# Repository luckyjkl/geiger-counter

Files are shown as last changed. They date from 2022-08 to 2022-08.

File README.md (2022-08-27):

# 盖革计数器

盖革管型号SI3BG，这个型号的盖革管价格便宜，量程比较大，灵敏度比较低，所以测量结果仅供参考。

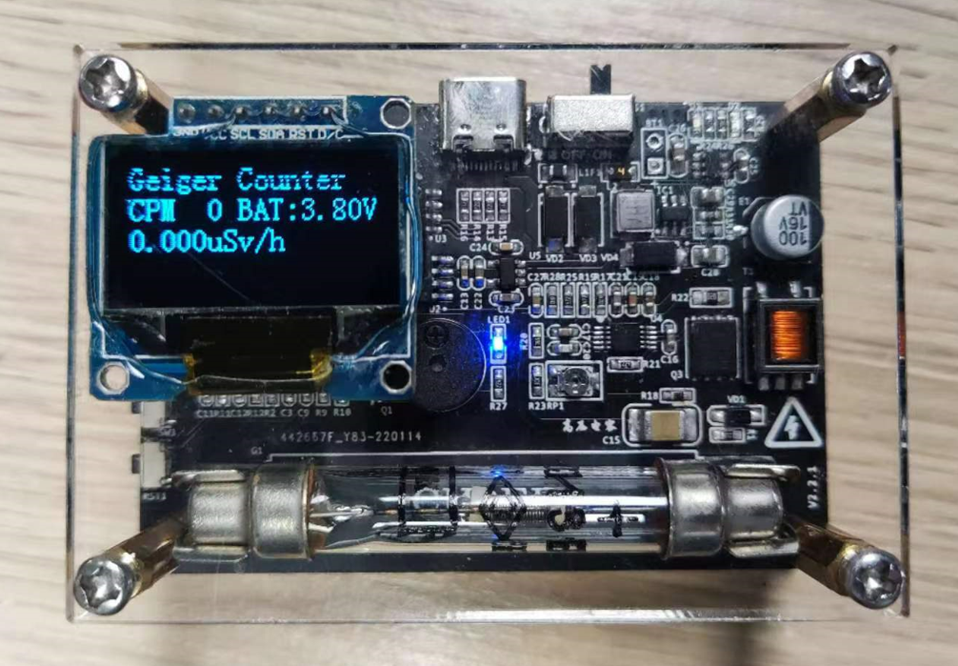
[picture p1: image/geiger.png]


## 1. 工程说明

### 1.1 参考设计

盖革管的测量电路设计参考[https://oshwhub.com/zhaokbk/si3bg_copy_copy](https://oshwhub.com/zhaokbk/si3bg_copy_copy)
盖革管电源驱动部分参考[https://oshwhub.com/zhaokbk/lm3481-gao-xiao-bian-ya-qi-hui-guang-guan-sheng-ya-mu-kuai](https://oshwhub.com/zhaokbk/lm3481-gao-xiao-bian-ya-qi-hui-guang-guan-sheng-ya-mu-kuai)

### 1.2 注意事项

1. OLED屏安装在左上角，屏幕的PCB会和铜柱发生干涉，所以只能将屏幕PCB锯掉一点，因为屏幕已经粘在亚克力板上，所以没有调整位置，介意的可以自行将屏幕右移。
2. 为什么加了一个5V的升压电路给盖革管驱动供电？去掉行不行？因为经过实测，要升压至400V，盖革管驱动部分的输入电压需要在3.8V以上，否则输出无法达到400V，且电压较高驱动电路部分的效率也较高，电压降低时功耗会急剧增大，影响续航。
3. 升压部分MOS管型号怎么选？
   * 选择导通阻抗低的，可以减小功耗。
   * 线圈副边升压至400V，匝数比1：10，所以原边MOS管的反向耐压值应该大于40V
4. 因为要提高盖革管驱动部分的效率，所以添加了一个5V的升压电路，系统不够简介，可以更换一个带5V输出的锂电池充电芯片，简化电路方案。
5. SWDIO口的接口型号为SH1.0-4P

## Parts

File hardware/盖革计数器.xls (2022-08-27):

Comment | Description | Designator | Footprint | LibRef | Quantity
DC5V | 蜂鸣器 | B1 | BEEP 5x9x5.5 | BEEP | 1
Battery 3.7V | Multicell Battery | BT1 | BAT-2 | Battery | 1
22 | 无极性贴片电容 | C1, C2 | C 0603 | C | 2
104 | 无极性贴片电容 | C3, C4, C5, C6, C7, C8, C11, C12, C13, C14, C27 | C 0603 | C | 11
220pF | 无极性贴片电容 | C9 | C 0603 | C | 1
103 | 无极性贴片电容 | C10, C24 | C 0603 | C | 2
1uF | 无极性贴片电容 | C15 | C 1812 | C | 1
1uF | 无极性贴片电容 | C16 | C 0603 | C | 1
22nF | 无极性贴片电容 | C17 | C 0603 | C | 1
100nF | 无极性贴片电容 | C18, C19 | C 0603 | C | 2
10pF | 无极性贴片电容 | C20 | C 0603 | C | 1
1nF | 无极性贴片电容 | C21 | C 0603 | C | 1
105 | 无极性贴片电容 | C22, C23, C25 | C 0603 | C | 3
10uF | 无极性贴片电容 | C26 | C 0805 | C | 1
22uF (226) 20% 25V | 贴片电容 | C28, C29 | 0805_C | 0805 22uF (226) 20% 25V | 2
红灯 0603 | 发光二极管 | D1 | 0603_LED_S1 | 0603 红灯 | 1
绿灯 0603 | 发光二极管 | D2 | 0603_LED_S1 | 0603 绿灯 | 1
100uF/16V | 贴片电解电容 | E1 | CM D(6.3*5.4) | C-CM | 1
0.5A | 贴片保险丝 | F1 | FU 0805 | FU | 1
盖革管 | 小型高量程SI3BG GM管 | G1 | SI3BG 2 | 盖革管 | 1
SX1308 | 可调升压芯片 | IC1 | SOT23-6N | SX1308 | 1
HDR-1X4 | 4P接插件 | JP1 | SH1.0-4P-L | Header 4 | 1
10um | 小功率贴片电感 | L1 | L 0805 | L | 1
4.7uH | 功率屏蔽电感 | L2 | L 04020 | L-CDRH | 1
红色 | 贴片LED | LED1 | LED 0603W | LED-SMD | 1
OLE 0.96-12864-7Pin |  | OLED1 | HDR-1X7_M | OLE 0.96-12864-7Pin | 1
S9013 | 低频放大-NPN型 | Q1, Q2 | SOT23-3N | 9013-SMD | 2
IRFH7440TRPBF | 40V/159A N沟道MOS管 | Q3 | PQFN8_5X6_B_INF | IRFH7440TRPBF | 1
2M | 贴片电阻 | R1 | R 0603 | R | 1
10K | 贴片电阻 | R2, R3, R5, R6, R8, R11, R12 | R 0603 | R | 7
0 | 贴片电阻 | R4 | R 0603 | R | 1
1K | 贴片电阻 | R7, R27, R28 | R 0603 | R | 3
22K | 贴片电阻 | R9 | R 0603 | R | 1
100K | 贴片电阻 | R10 | R 0603 | R | 1
10 | 贴片电阻 | R13, R14 | R 0603 | R | 2
5.1K | 贴片电阻 | R15, R16 | R 0603 | R | 2
121K | 贴片电阻 | R17, R19 | R 0603 | R | 2
10M | 贴片电阻 | R18 | R 0603 | R | 1
40.2K | 贴片电阻 | R20 | R 0603 | R | 1
220K | 贴片电阻 | R21 | R 0603 | R | 1
0.02 | 贴片电阻 | R22 | R 0805 | R | 1
20K | 贴片电阻 | R23 | R 0603 | R | 1
4.7K | 贴片电阻 | R24, R25, R29 | R 0603 | R | 3
3K | 贴片电阻 | R26 | R 0603 | R | 1
110KΩ (1103) ±1% | 贴片电阻 | R30 | 0603_R | 0603 110KΩ (1103) 1% | 1
15KΩ (1502) ±1% | 贴片电阻 | R31 | 0603_R | 0603 15KΩ (1502) 1% | 1
10K | 贴片电位器 | RP1 | 3303W | RP-SMD | 1
TSW | 轻触开关 | RST1, SW1, SW2, SW3 | TSW 2*4*3.5-S-W | TSW SMD | 4
SS-12F23 | 1路拨动开关 | S1 | SS-12D07 | SSW-1P | 1
TTRN-060S-013-T | 1:10.5 3.2A 贴片闪光灯变压器 | T1 | EE5.0 | TTRN-060S-013-T | 1
STM32F103C | STM32单片机48引脚 | U1 | LQFP-48_M | STM32F103C | 1
W25QXX | SPI FLASH | U2 | SOIC8_W | W25QXX | 1
CH330 |  | U3 | SOIC8_N | CH330 | 1
LM3481 | High-Efficiency Controller for Boost, SEPIC and Flyback DC-DC Converters | U4 | VSSOP10 | LM3481 | 1
SGM2028-3.3YN5G | 500mA,3.3V低压差线性稳压器 | U5 | SOT23-5 | SGM2028-3.3YN5G | 1
TP4059 | 600mA单节锂电池充电芯片 | U6 | SOT23-6_N | TP4059 | 1
USB | USB-C型母口16P/12P | USB1 | USB-C/16P | USB-C/16P | 1
E1J | 600V/1A 超快恢复二极管 | VD1 | SOD-123F | E1J | 1
SS54 | 肖特基二极管 | VD2, VD3 | SMA | SS14 | 2
SS34 | 肖特基二极管 | VD4 | SMA | SS14 | 1
8M | 4脚晶振 | X1 | XTAL-3225 | XTAL-4 | 1

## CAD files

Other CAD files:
盖板.dwg

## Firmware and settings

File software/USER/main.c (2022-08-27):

#include "stm32f10x.h"
#include <stdio.h>
#include "oled.h"
#include "pwm.h"
#include "exti.h"
#include "usart.h"
#include "delay.h"
#include "timer.h"
#include "beep.h"
#include "adc.h"
#include "sample_timer.h"

//151CPM=1uSv/h,计数和辐射量转换公式

//extern int Geiger_Count;
//extern int Last_Geiger_Count;
//extern float volatile Count_Time;
extern int volatile Count_Sum;
////float radiation_dose = 0;
//extern char volatile Count_Queue[MAX_QUEUE_LENGTH];

int main()
{
//	u16 volatile pwmval;	
//	pwmval = 13999;
	delay_init();
	uart_init(115200);
	EXTIX_Init();
	NVIC_PriorityGroupConfig(NVIC_PriorityGroup_2);     //设置中断分组
	SPI_OLED_Init();
    Battery_ADC_Init();
	
	TIM3_Init(9999, 719);			//频率100K，计数时间0.1s
    Sample_Timer_Init();
	BEEP_Init();					//蜂鸣器初始化
	
	OLED_ShowString(0, 0, "Geiger Counter");
	OLED_ShowString(0, 2, "CPM");
    
    OLED_ShowNum(24, 2, Count_Sum, 3, 16);
    Show_Radiation_Dose();
    OLED_Show_Voltage();
	
	while(1)
	{
//		OLED_ShowNum(24, 2, Count_Sum, 3, 16);
//		Show_Radiation_Dose();
//		if(Last_Geiger_Count < Geiger_Count)
//		{
//			Last_Geiger_Count = Geiger_Count;
//			BEEP_ON;
//		}
//		delay_ms(100);
//		BEEP_OFF;
//		printf("test\r\n");
	}
}

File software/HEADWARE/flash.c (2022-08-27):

#include "flash.h" 
//#include "spi.h"
#include "delay.h"   
//Mini STM32开发板
//W25X16 驱动函数 
//正点原子@ALIENTEK
//2010/6/13
//V1.0
u16 SPI_FLASH_TYPE=W25Q64;//默认就是25Q64
//4Kbytes为一个Sector
//16个扇区为1个Block
//W25X16
//容量为2M字节,共有32个Block,512个Sector

SPI_InitTypeDef SPI_InitType;

//初始化SPI FLASH的IO口
void SPI_Flash_Init(void)
{
	GPIO_InitTypeDef GPIO_InitStructure;
	SPI_InitTypeDef SPI_InitType;

	RCC_APB2PeriphClockCmd(SPI_FLASH_CS_RCC, ENABLE);

	GPIO_InitStructure.GPIO_Pin = SPI_FLASH_CS;  //SPI CS
 	GPIO_InitStructure.GPIO_Mode = GPIO_Mode_Out_PP;  //复用推挽输出
	GPIO_InitStructure.GPIO_Speed = GPIO_Speed_50MHz;
 	GPIO_Init(SPI_FLASH_CS_GPIO, &GPIO_InitStructure);
 	GPIO_SetBits(SPI_FLASH_CS_GPIO, SPI_FLASH_CS);
	
	RCC_APB2PeriphClockCmd(Flash_GPIO_RCC, ENABLE);		//GPIO,SPI使能
	RCC_APB1PeriphClockCmd(Flash_SPI_RCC, ENABLE);

	GPIO_InitStructure.GPIO_Pin = Flash_SPI_SCK | Flash_SPI_MISO | Flash_SPI_MOSI;
	GPIO_InitStructure.GPIO_Mode = GPIO_Mode_AF_PP;								//复用推挽输出
	GPIO_InitStructure.GPIO_Speed = GPIO_Speed_50MHz;
	GPIO_Init(Flash_SPI_GPIO, &GPIO_InitStructure);									//GPIO初始化
	GPIO_SetBits(Flash_SPI_GPIO, Flash_SPI_SCK | Flash_SPI_MISO | Flash_SPI_MOSI);	//IO输出高
	
	SPI_InitType.SPI_Direction = SPI_Direction_2Lines_FullDuplex;		//SPI设置全双工
	SPI_InitType.SPI_Mode = SPI_Mode_Master;							//SPI设置为主SPI
	SPI_InitType.SPI_CPOL = SPI_CPOL_High;								//稳态时钟高
	SPI_InitType.SPI_CPHA = SPI_CPHA_2Edge;								//数据捕获于第二个时钟沿
	SPI_InitType.SPI_DataSize = SPI_DataSize_8b;						//八位帧结构
	SPI_InitType.SPI_NSS = SPI_NSS_Soft;								//NSS信号由软件控制
	SPI_InitType.SPI_BaudRatePrescaler = SPI_BaudRatePrescaler_4;		//预分频4
	SPI_InitType.SPI_FirstBit = SPI_FirstBit_MSB;						//传输数据从MSE位开始
	SPI_InitType.SPI_CRCPolynomial = 7;									//CRC值计算的多项式
	SPI_Init(Flash_SPI, &SPI_InitType);										//初始化SPI1
	
	SPI_Cmd(Flash_SPI, ENABLE);		//使能SPI外设
	
	SPIx_ReadWriteByte(0xff);
//	SPI1_Init();		   //初始化SPI
//	SPI1_SetSpeed(SPI_BaudRatePrescaler_4);	//设置为18M时钟,高速模式
	SPI_FLASH_TYPE=SPI_Flash_ReadID();//读取FLASH ID.
}  

//读取SPI_FLASH的状态寄存器
//BIT7  6   5   4   3   2   1   0
//SPR   RV  TB BP2 BP1 BP0 WEL BUSY
//SPR:默认0,状态寄存器保护位,配合WP使用
//TB,BP2,BP1,BP0:FLASH区域写保护设置
//WEL:写使能锁定
//BUSY:忙标记位(1,忙;0,空闲)
//默认:0x00
u8 SPI_Flash_ReadSR(void)   
{  
	u8 byte=0;   
	SPI_FLASH_CS_LOW;                           //使能器件   
	SPIx_ReadWriteByte(W25X_ReadStatusReg);    	//发送读取状态寄存器命令    
	byte=SPIx_ReadWriteByte(0Xff);             	//读取一个字节  
	SPI_FLASH_CS_HIGH;                          //取消片选     
	return byte;   
} 
//写SPI_FLASH状态寄存器
//只有SPR,TB,BP2,BP1,BP0(bit 7,5,4,3,2)可以写!!!
void SPI_FLASH_Write_SR(u8 sr)   
{   
	SPI_FLASH_CS_LOW;                           //使能器件   
	SPIx_ReadWriteByte(W25X_WriteStatusReg);   	//发送写取状态寄存器命令    
	SPIx_ReadWriteByte(sr);               		//写入一个字节  
	SPI_FLASH_CS_HIGH;                          //取消片选     	      
}   
//SPI_FLASH写使能	
//将WEL置位   
void SPI_FLASH_Write_Enable(void)   
{
	SPI_FLASH_CS_LOW;                           //使能器件   
    SPIx_ReadWriteByte(W25X_WriteEnable);      	//发送写使能  
	SPI_FLASH_CS_HIGH;                          //取消片选     	      
} 
//SPI_FLASH写禁止	
//将WEL清零  
void SPI_FLASH_Write_Disable(void)   
{  
	SPI_FLASH_CS_LOW;                            //使能器件   
    SPIx_ReadWriteByte(W25X_WriteDisable);     //发送写禁止指令    
	SPI_FLASH_CS_HIGH;                            //取消片选     	      
} 			    
//读取芯片ID W25X16的ID:0XEF14
u16 SPI_Flash_ReadID(void)
{
	u16 Temp = 0;	  
	SPI_FLASH_CS_LOW;				    
	SPIx_ReadWriteByte(0x90);//发送读取ID命令	    
	SPIx_ReadWriteByte(0x00); 	    
	SPIx_ReadWriteByte(0x00); 	    
	SPIx_ReadWriteByte(0x00); 	 			   
	Temp |= SPIx_ReadWriteByte(0xFF)<<8;  
	Temp |= SPIx_ReadWriteByte(0xFF);	 
	SPI_FLASH_CS_HIGH;				    
	return Temp;
}   		    
//读取SPI FLASH  
//在指定地址开始读取指定长度的数据
//pBuffer:数据存储区
//ReadAddr:开始读取的地址(24bit)
//NumByteToRead:要读取的字节数(最大65535)
void SPI_Flash_Read(u8* pBuffer,u32 ReadAddr,u16 NumByteToRead)   
{ 
 	u16 i;    												    
	SPI_FLASH_CS_LOW;                            //使能器件   
    SPIx_ReadWriteByte(W25X_ReadData);         //发送读取命令   
    SPIx_ReadWriteByte((u8)((ReadAddr)>>16));  //发送24bit地址    
    SPIx_ReadWriteByte((u8)((ReadAddr)>>8));   
    SPIx_ReadWriteByte((u8)ReadAddr);   
    for(i=0;i<NumByteToRead;i++)
	{ 
        pBuffer[i]=SPIx_ReadWriteByte(0XFF);   //循环读数  
    }
	SPI_FLASH_CS_HIGH;                            //取消片选     	      
}  
//SPI在一页(0~65535)内写入少于256个字节的数据
//在指定地址开始写入最大256字节的数据
//pBuffer:数据存储区
//WriteAddr:开始写入的地址(24bit)
//NumByteToWrite:要写入的字节数(最大256),该数不应该超过该页的剩余字节数!!!	 
void SPI_Flash_Write_Page(u8* pBuffer,u32 WriteAddr,u16 NumByteToWrite)
{
 	u16 i;  
    SPI_FLASH_Write_Enable();                  //SET WEL 
	SPI_FLASH_CS_LOW;                            //使能器件   
    SPIx_ReadWriteByte(W25X_PageProgram);      //发送写页命令   
    SPIx_ReadWriteByte((u8)((WriteAddr)>>16)); //发送24bit地址    
    SPIx_ReadWriteByte((u8)((WriteAddr)>>8));   
    SPIx_ReadWriteByte((u8)WriteAddr);   
    for(i=0;i<NumByteToWrite;i++)SPIx_ReadWriteByte(pBuffer[i]);//循环写数  
	SPI_FLASH_CS_HIGH;                            //取消片选 
	SPI_Flash_Wait_Busy();					   //等待写入结束
} 
//无检验写SPI FLASH 
//必须确保所写的地址范围内的数据全部为0XFF,否则在非0XFF处写入的数据将失败!
//具有自动换页功能 
//在指定地址开始写入指定长度的数据,但是要确保地址不越界!
//pBuffer:数据存储区
//WriteAddr:开始写入的地址(24bit)
//NumByteToWrite:要写入的字节数(最大65535)
//CHECK OK
void SPI_Flash_Write_NoCheck(u8* pBuffer,u32 WriteAddr,u16 NumByteToWrite)   
{ 			 		 
	u16 pageremain;	   
	pageremain=256-WriteAddr%256; //单页剩余的字节数		 	    
	if(NumByteToWrite<=pageremain)pageremain=NumByteToWrite;//不大于256个字节
	while(1)
	{	   
		SPI_Flash_Write_Page(pBuffer,WriteAddr,pageremain);
		if(NumByteToWrite==pageremain)break;//写入结束了
	 	else //NumByteToWrite>pageremain
		{
			pBuffer+=pageremain;
			WriteAddr+=pageremain;	

			NumByteToWrite-=pageremain;			  //减去已经写入了的字节数
			if(NumByteToWrite>256)pageremain=256; //一次可以写入256个字节
			else pageremain=NumByteToWrite; 	  //不够256个字节了
		}
	};	    
}
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

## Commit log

2022-08-27 添加gitignore文件
2022-08-27 添加README
2022-08-27 亚克力盖板
    [盖板.dwg]
2022-08-27 添加文件
    [CORE.SchDoc, POWER.SchDoc, geiger counter.PcbDoc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]
2022-08-27 添加图片
2022-08-27 修改说明
2022-08-27 修改说明文件
2022-08-27 添加BOM
    [盖革计数器.xls]
